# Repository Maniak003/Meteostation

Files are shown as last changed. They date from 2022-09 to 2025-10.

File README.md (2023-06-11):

<!DOCTYPE html>
<html lang="en" data-color-mode="auto" data-light-theme="light" data-dark-theme="dark">
  <head>
    <meta charset="utf-8">
  </head>
    <body class="logged-in env-production page-responsive page-blob" style="word-wrap: break-word;">
      <p> Meteostation with radiation monitor. </p>
      <a href="https://github.com/Maniak003/Meteostation/wiki" rel="nofollow">
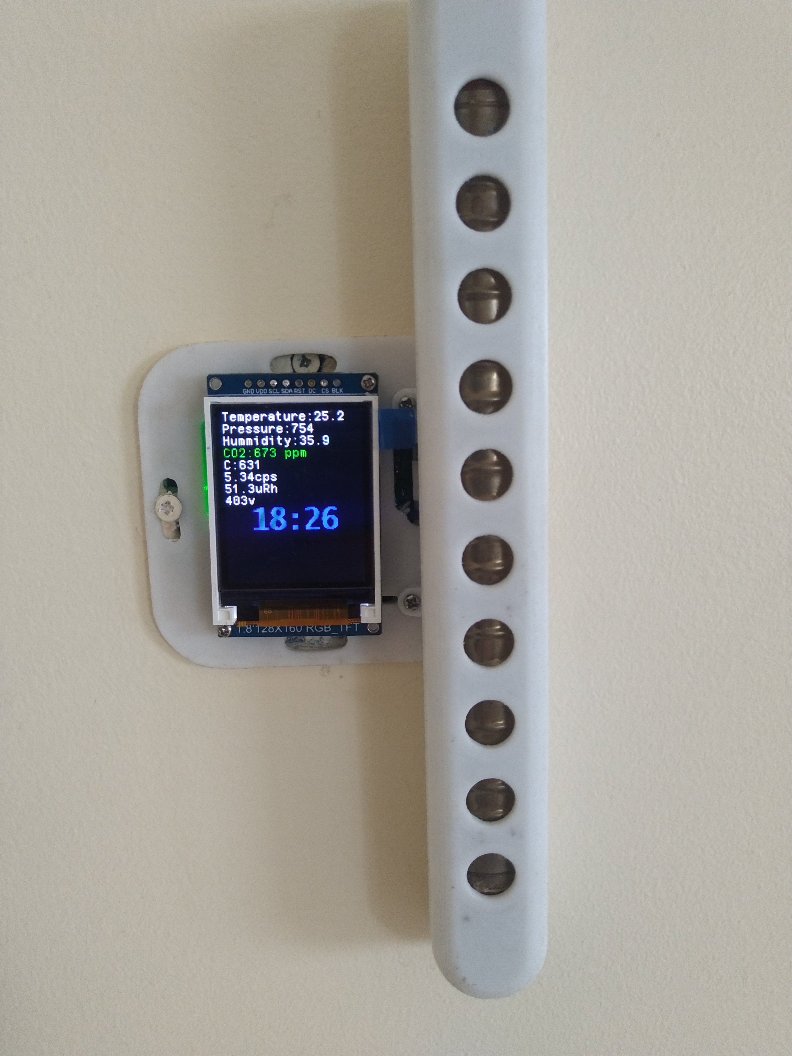
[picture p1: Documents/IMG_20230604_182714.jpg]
        
      </a>
      <a href="https://github.com/Maniak003/Meteostation/wiki" rel="nofollow">
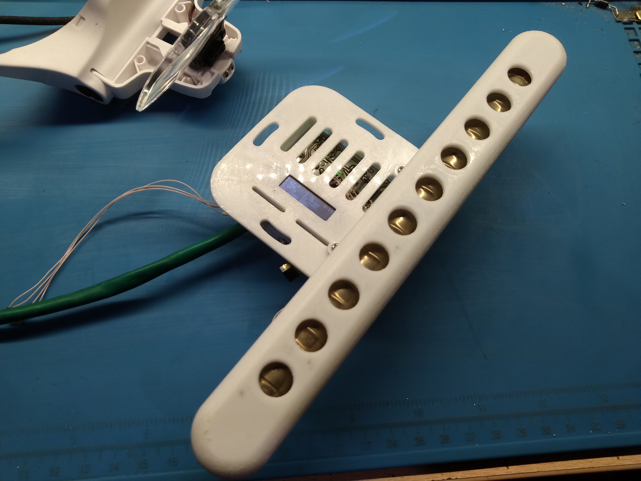
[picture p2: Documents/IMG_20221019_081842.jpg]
        
      </a>
      <a href="https://github.com/Maniak003/HVoltmeter/wiki" rel="nofollow">
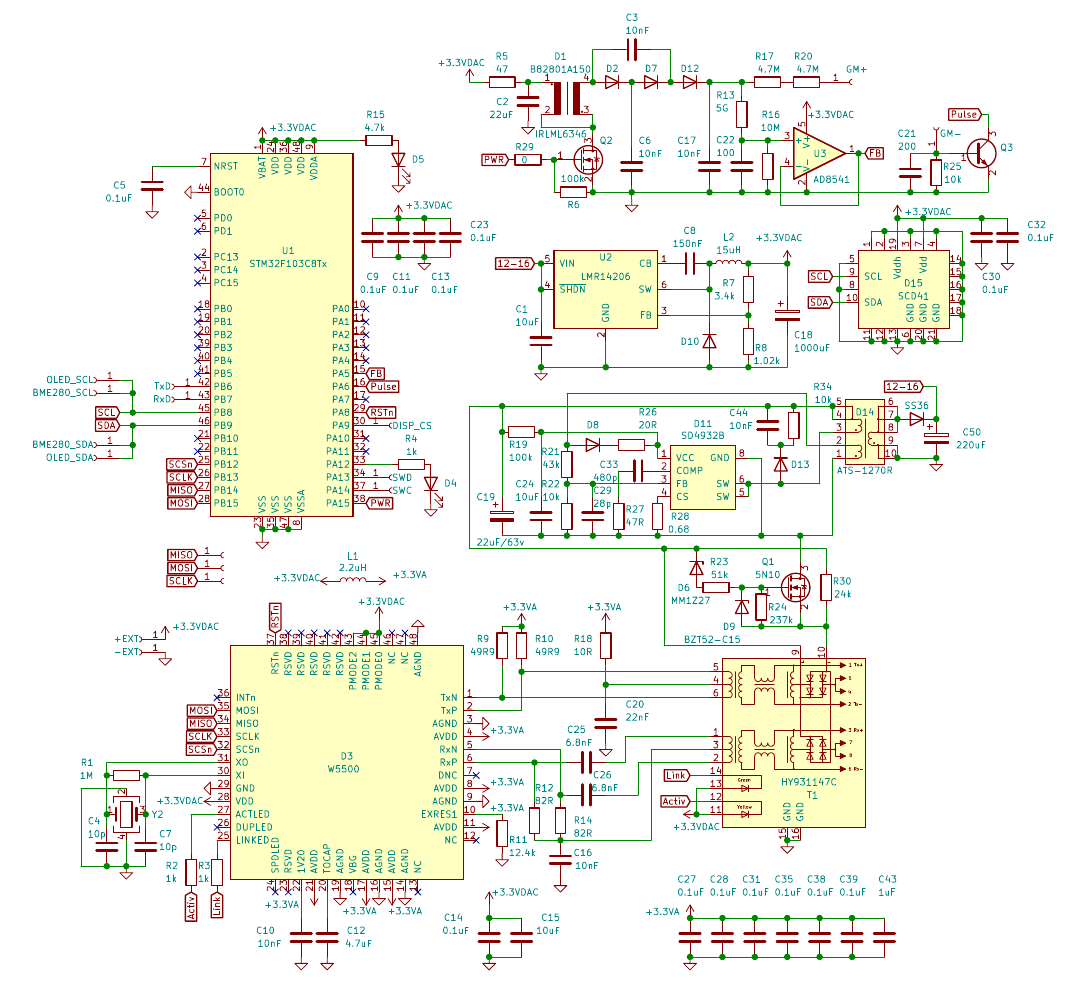
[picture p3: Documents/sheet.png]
        
      </a>
    </body>
</html>

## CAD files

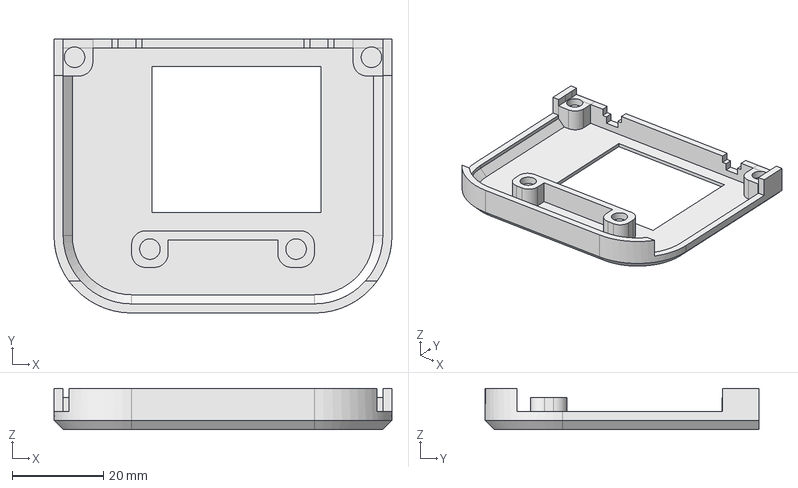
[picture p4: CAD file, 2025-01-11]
FreeCAD/face.FCStd
74.0 x 60.0 x 9.00 mm

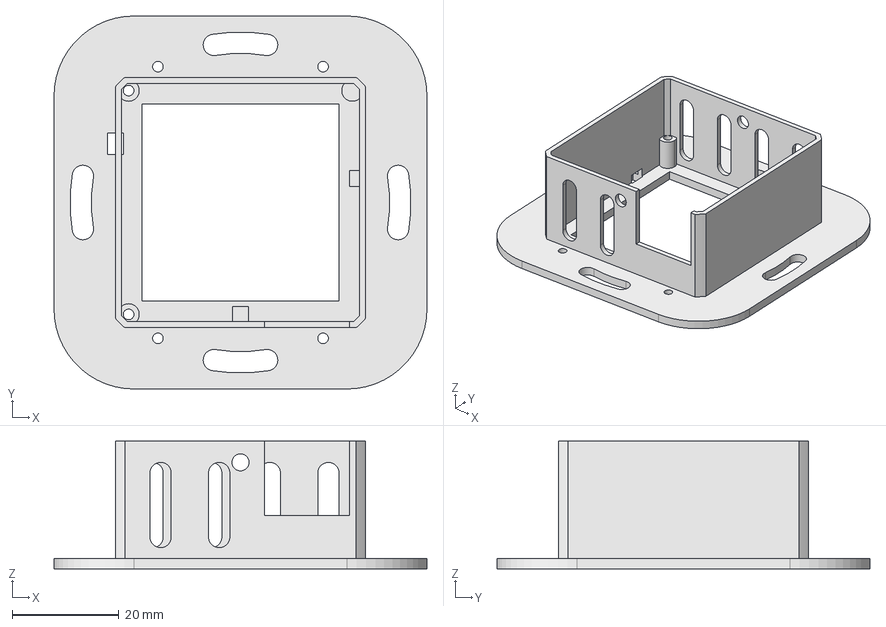
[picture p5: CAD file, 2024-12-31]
FreeCAD/box3.FCStd
70.0 x 70.0 x 24.0 mm

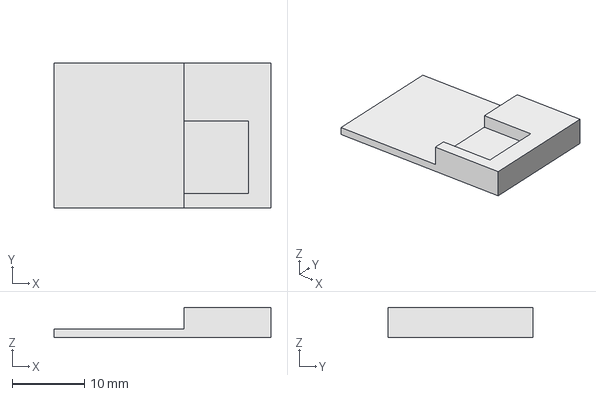
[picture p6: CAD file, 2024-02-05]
FreeCAD/co2holder.FCStd
30.0 x 20.0 x 4.20 mm

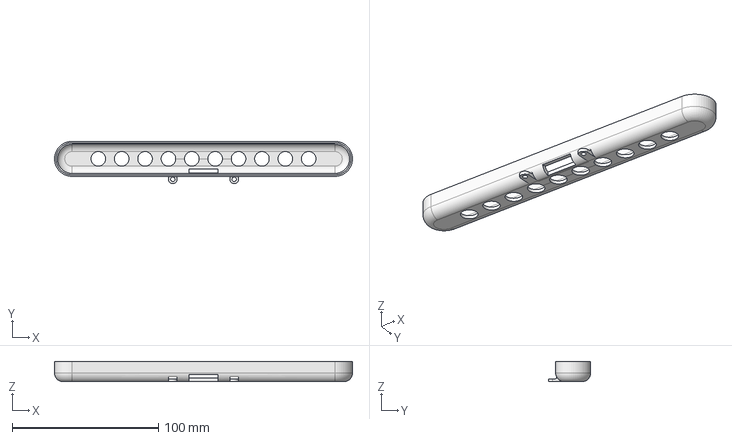
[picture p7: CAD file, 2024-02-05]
FreeCAD/GM_case.FCStd
204.0 x 29.0 x 14.0 mm

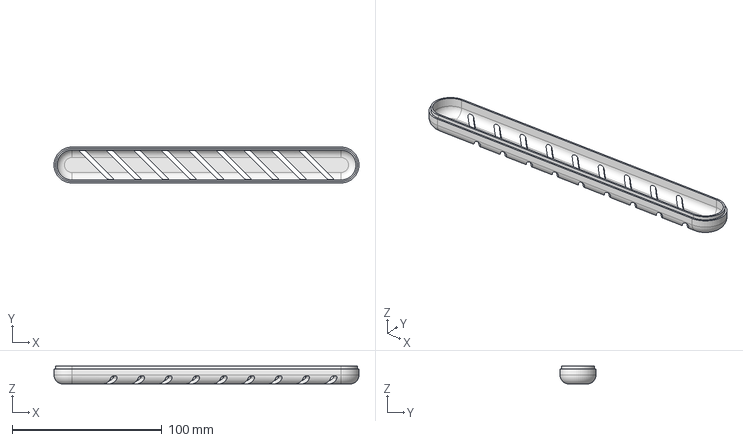
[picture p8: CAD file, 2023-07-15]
FreeCAD/GM_case_top-2.FCStd
204.0 x 24.0 x 12.0 mm

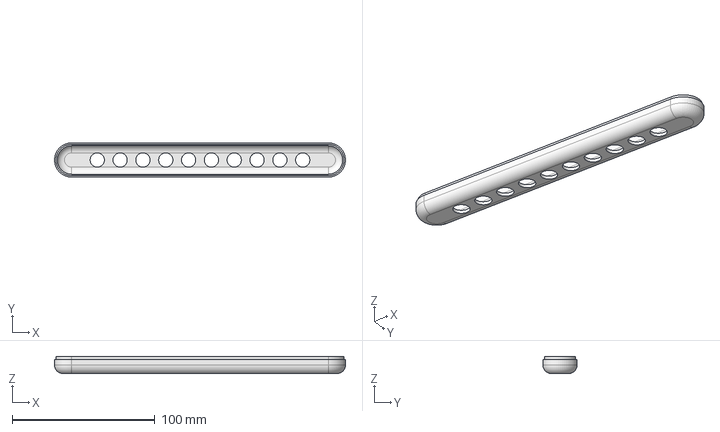
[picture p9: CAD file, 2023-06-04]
FreeCAD/GM_case_top.FCStd
204.0 x 24.0 x 12.0 mm

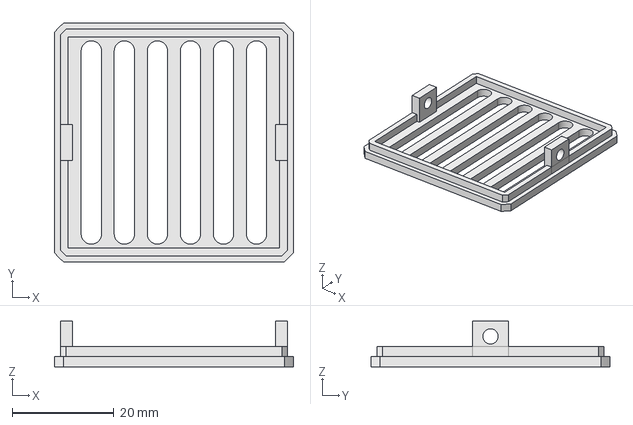
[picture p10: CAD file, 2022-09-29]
FreeCAD/cover.FCStd
47.0 x 47.0 x 9.00 mm

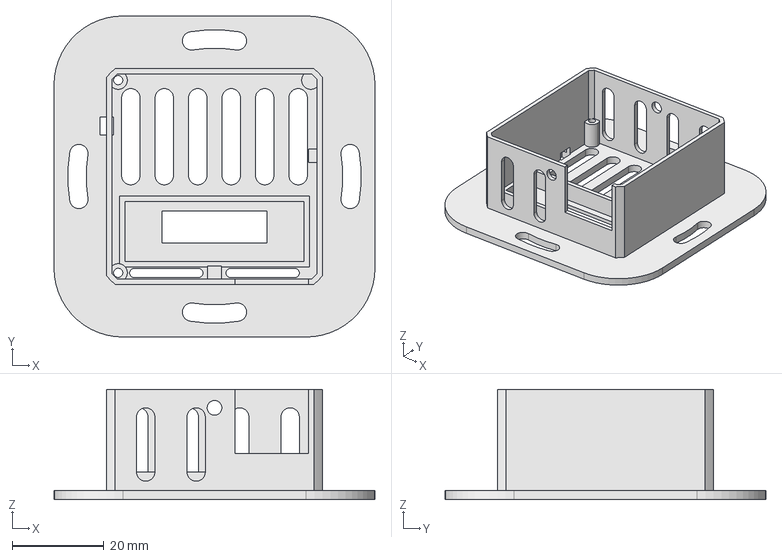
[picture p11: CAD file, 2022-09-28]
FreeCAD/box2.FCStd
70.0 x 70.0 x 24.0 mm

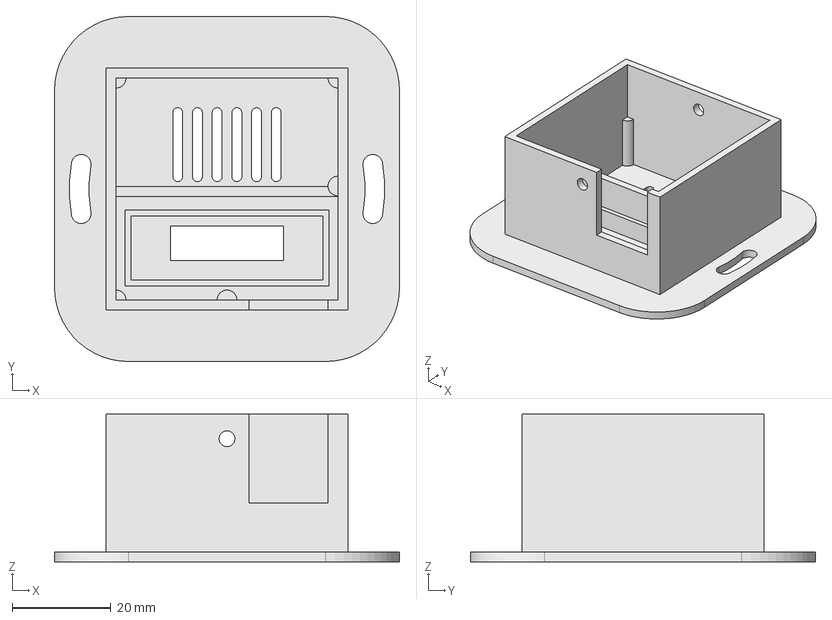
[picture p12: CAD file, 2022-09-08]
FreeCAD/box.FCStd
70.0 x 70.0 x 30.0 mm

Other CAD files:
FreeCAD/box.stl
FreeCAD/box2.stl

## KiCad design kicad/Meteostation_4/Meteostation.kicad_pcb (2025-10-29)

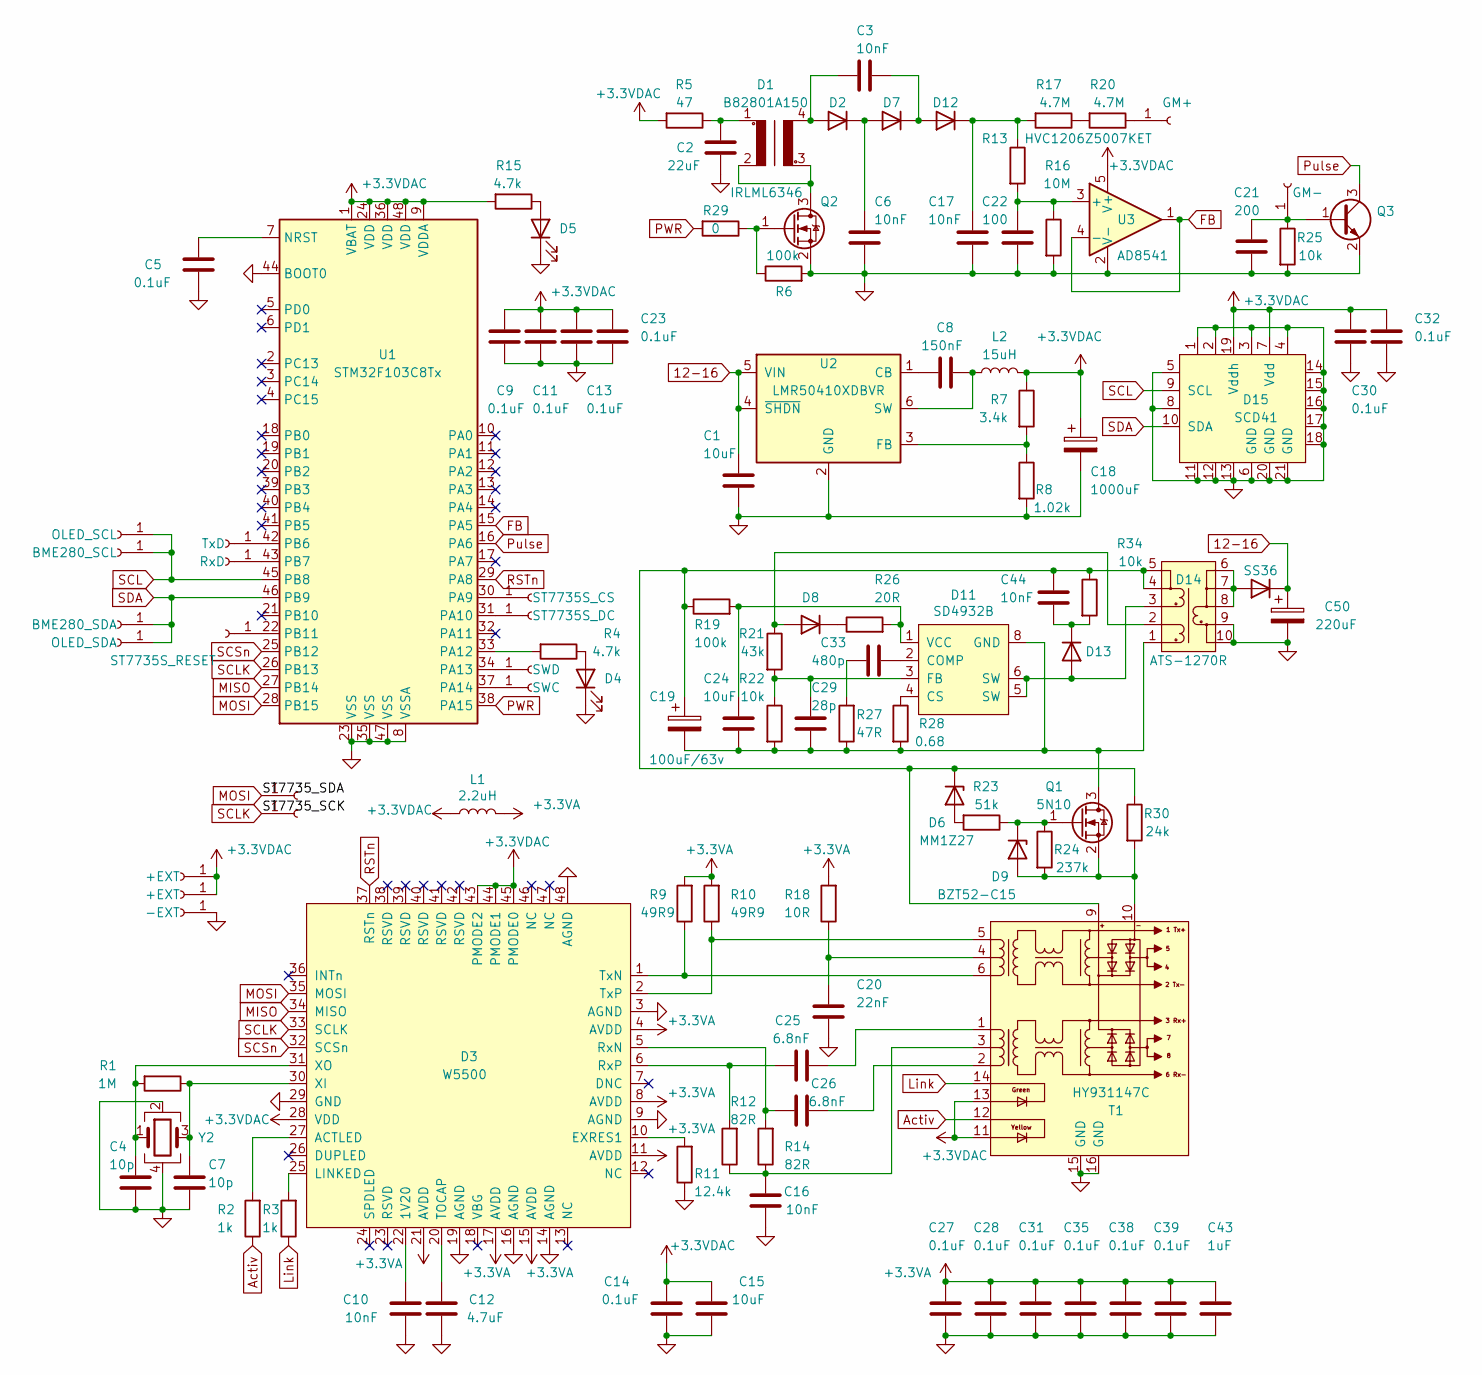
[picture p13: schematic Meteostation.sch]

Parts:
C1, C24: 10uF; C_0805_2012Metric
C2: 22uF; C_0805_2012Metric
C3, C6, C17: 10nF; C_1206_3216Metric
C4, C7: 10p; C_0402_1005Metric
C5, C14, C27, C28, C31, C35, C38, C39: 0.1uF; C_0402_1005Metric
C8: 150nF; C_0603_1608Metric
C9, C11, C13, C30, C32: 0.1uF; C_0603_1608Metric
C10: 10nF; C_0402_1005Metric
C12: 4.7uF; C_0402_1005Metric
C15: 10uF; C_0603_1608Metric
C16, C44: 10nF; C_0603_1608Metric
C18: 1000uF; CP_EIA-7343-15_Kemet-W
C19: 100uF/63v; CAP_horizontal
C20: 22nF; C_0603_1608Metric
C21: 200; C_0402_1005Metric
C22: 100; C_0402_1005Metric
C23: 0.1uF; C_0805_2012Metric
C25, C26: 6.8nF; C_0402_1005Metric
C29: 28p; C_0603_1608Metric
C33: 480p; C_0603_1608Metric
C43: 1uF; C_0402_1005Metric
C50: 220uF; CP_EIA-7343-15_Kemet-W
D1: B82801A150; B82801A1
D2, D7, D12: D; D_SOD-123
D3: W5500; LQFP-48_7x7mm_P0.5mm
D4, D5: LED; LED_0603_1608Metric
D6: MM1Z27; D_SOD-123
D8, D13: FR107W F7; D_SOD-123F
D9: BZT52-C15; D_SOD-123
D11: SD4932B; SOIC-8-N7_3.9x4.9mm_P1.27mm
D14: ATS-1270R; DA2257
D15: SCD41
D16: SS36; D_SMA
J1: TxD; ConnMini
J2: RxD; ConnMini
J3: BME280_SCL; SMD-CONN
J4: BME280_SDA; SMD-CONN
J5: +EXT; ConnMini
J6: +EXT; SMD-CONN
J7: -EXT; SMD-CONN
J8: mosi; ConnMini
J9: sclk; ConnMini
J10: GM+; SMD-CONN
J11: GM-; SMD-CONN
J12: SWD; ConnMini
J13: SWC; ConnMini
J14: ST7735S_CS; mini_conn
J15: OLED_SCL; SMD-CONN
J16: OLED_SDA; SMD-CONN
J17: ST7735S_DC; mini_conn
J18: ST7735S_RESET; mini_conn
L1: 2.2uH; L_0805_2012Metric
L2: 15uH; L_Abracon_ASPI-0630LR
Q1: 5N10; SOT-23
Q2: IRLML6346; SOT-23
Q3: Q_NPN_BEC; SOT-23
R1: 1M; R_0402_1005Metric
R2, R3: 1k; R_0402_1005Metric
R4: 4.7k; R_0402_1005Metric
R5: 47; R_1206_3216Metric
R6, R19: 100k; R_0603_1608Metric
R7: 3.4k; R_0603_1608Metric
R8: 1.02k; R_0603_1608Metric
R9, R10: 49R9; R_0603_1608Metric
R11: 12.4k; R_0402_1005Metric
R12, R14: 82R; R_0402_1005Metric
R13: HVC1206Z5007KET; R_1206_3216Metric
R15: 4.7k; R_0603_1608Metric
R16: 10M; R_0402_1005Metric
R17, R20: 4.7M; R_0603_1608Metric
R18: 10R; R_0603_1608Metric
R21: 43k; R_0603_1608Metric
R22, R34: 10k; R_0603_1608Metric
R23: 51k; R_0603_1608Metric
R24: 237k; R_0603_1608Metric
R25: 10k; R_0402_1005Metric
R26: 20R; R_0603_1608Metric
R27: 47R; R_0603_1608Metric
R28: 0.68; R_0603_1608Metric
R29: 0; R_1206_3216Metric
R30: 24k; R_0603_1608Metric
T1: HY931147C
U1: STM32F103C8Tx; LQFP-48_7x7mm_P0.5mm
U2: LMR50410XDBVR; SOT-23-6
U3: AD8541; TSOT-23-5
Y2: ECS-250-20-33 25MHz; Crystal_SMD_SeikoEpson_FA238-4Pin_3.2x2.5mm

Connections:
12-16: C1.1, C50.1, D16.1 (K), U2.4 (~SHDN), U2.5 (VIN)
+3.3VA: C27.1, C28.1, C31.1, C35.1, C38.1, C39.1, C43.1, D3.4 (AVDD), D3.8 (AVDD), D3.11 (AVDD), D3.15 (AVDD), D3.17 (AVDD), D3.21 (AVDD), L1.2, R9.2, R10.2, R18.2
+3.3VDAC: C9.1, C11.1, C13.1, C14.2, C15.2, C18.1, C23.1, C30.1, C32.1, D3.28 (VDD), D3.43 (PMODE2), D3.44 (PMODE1), D3.45 (PMODE0), D15.7 (Vdd), D15.19 (Vddh), J5.1, J6.1, L1.1, L2.2, R5.2, R7.1, R15.2, T1.11, T1.13, U1.1 (VBAT), U1.9 (VDDA), U1.24 (VDD), U1.36 (VDD), U1.48 (VDD), U3.5 (V+)
Activ: R2.1, T1.12
FB: U1.15 (PA5), U3.1, U3.4 (-)
GND: C1.2, C2.2, C4.2, C5.1, C6.2, C7.2, C9.2, C10.1, C11.2, C12.1, C13.2, C14.1, C15.1, C16.1, C17.2, C18.2, C20.2, C21.1, C22.1, C23.2, C27.2, C28.2, C30.2, C31.2, C32.2, C35.2, C38.2, C39.2, C43.2, C50.2, D3.3 (AGND), D3.9 (AGND), D3.14 (AGND), D3.16 (AGND), D3.19 (AGND), D3.29 (GND), D3.48 (AGND), D4.1 (K), D5.1 (K), D14.9, D14.10, D15.1, D15.2, D15.3, D15.4, D15.5, D15.6 (GND), D15.8, D15.11, D15.12, D15.13, D15.14, D15.15, D15.16, D15.17, D15.18, D15.20 (GND), D15.21 (GND), J7.1, Q2.2 (S), Q3.2 (E), R6.2, R8.2, R11.1, R16.2, R25.2, T1.15 (GND), T1.16 (GND), U1.8 (VSSA), U1.23 (VSS), U1.35 (VSS), U1.44 (BOOT0), U1.47 (VSS), U2.2 (GND), U3.2 (V-), Y2.2, Y2.4
Link: R3.1, T1.14
MISO: D3.34 (MISO), U1.27 (PB14)
MOSI: D3.35 (MOSI), J8.1, U1.28 (PB15)
unnamed: C2.1, D1.1, R5.1
unnamed: C16.2, R12.1, R14.1, T1.3
unnamed: C20.1, R18.1, T1.4
unnamed: C25.2, T1.1
unnamed: C26.2, T1.2
unnamed: C33.2, R27.2
unnamed: C3.2, D1.4, D2.2 (A)
unnamed: C6.1, D2.1 (K), D7.2 (A)
unnamed: C10.2, D3.22 (1V20)
unnamed: D3.27 (ACTLED), R2.2
unnamed: D3.10 (EXRES1), R11.2
unnamed: D3.25 (LINKED), R3.2
unnamed: C26.1, D3.5 (RxN), R14.2
unnamed: C25.1, D3.6 (RxP), R12.2
unnamed: C12.2, D3.20 (TOCAP)
unnamed: D3.1 (TxN), R9.1, T1.6
unnamed: D3.2 (TxP), R10.1, T1.5
unnamed: C7.1, D3.30 (XI), R1.1, Y2.3
unnamed: C4.1, D3.31 (XO), R1.2, Y2.1
unnamed: D4.2 (A), R4.1
unnamed: D5.2 (A), R15.1
unnamed: D6.2 (A), R23.2
unnamed: C19.1, C44.1, D6.1 (K), D14.4, D14.5, R19.1, R30.1, R34.1, T1.9
unnamed: D8.2 (A), D14.2, R21.1
unnamed: D8.1 (K), R26.1
unnamed: D9.2 (A), Q1.2 (S), R24.2, R30.2, T1.10
unnamed: D9.1 (K), Q1.1 (G), R23.1, R24.1
unnamed: C33.1, D11.2 (COMP)
unnamed: D11.4 (CS), R28.1
unnamed: C29.1, D11.3 (FB), R21.2, R22.1
unnamed: C19.2, C24.2, C29.2, D11.8 (GND), D14.1, Q1.3 (D), R22.2, R27.1, R28.2
unnamed: C24.1, D11.1 (VCC), R19.2, R26.2
unnamed: C3.1, D7.1 (K), D12.2 (A)
unnamed: C17.1, D12.1 (K), R13.1, R17.2
unnamed: D11.5 (SW), D11.6 (SW), D13.2 (A), D14.3
unnamed: C44.2, D13.1 (K), R34.2
unnamed: D14.6, D14.7, D14.8, D16.2 (A)
unnamed: J1.1, U1.42 (PB6)
unnamed: J2.1, U1.43 (PB7)
unnamed: J10.1, R20.1
unnamed: C21.2, J11.1, Q3.1 (B), R25.1
unnamed: J12.1, U1.34 (PA13)
unnamed: J13.1, U1.37 (PA14)
unnamed: J14.1, U1.30 (PA9)
unnamed: J17.1, U1.31 (PA10)
unnamed: J18.1, U1.22 (PB11)
unnamed: D1.2, D1.3, Q2.3 (D)
unnamed: Q2.1 (G), R6.1, R29.1
unnamed: R17.1, R20.2
unnamed: C5.2, U1.7 (NRST)
unnamed: R4.2, U1.33 (PA12)
unnamed: C8.1, U2.1 (CB)
unnamed: R7.2, R8.1, U2.3 (FB)
unnamed: C8.2, L2.1, U2.6 (SW)
unnamed: C22.2, R13.2, R16.1, U3.3 (+)
PWR: R29.2, U1.38 (PA15)
Pulse: Q3.3 (C), U1.16 (PA6)
RSTn: D3.37 (RSTn), U1.29 (PA8)
SCL: D15.9 (SCL), J3.1, J15.1, U1.45 (PB8)
SCLK: D3.33 (SCLK), J9.1, U1.26 (PB13)
SCSn: D3.32 (SCSn), U1.25 (PB12)
SDA: D15.10 (SDA), J4.1, J16.1, U1.46 (PB9)

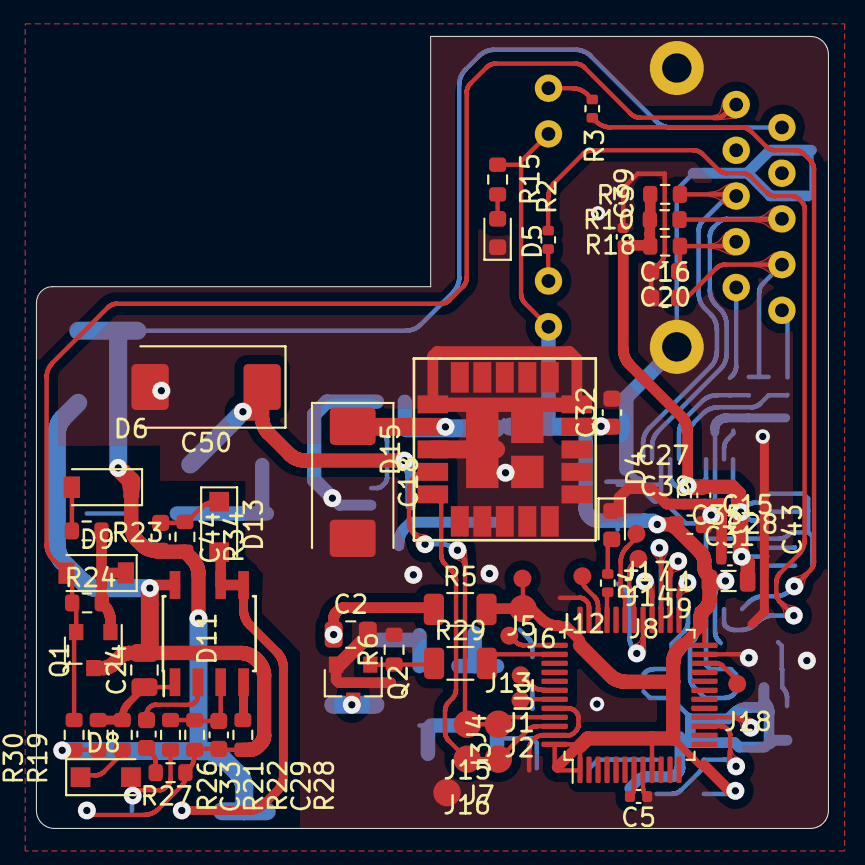
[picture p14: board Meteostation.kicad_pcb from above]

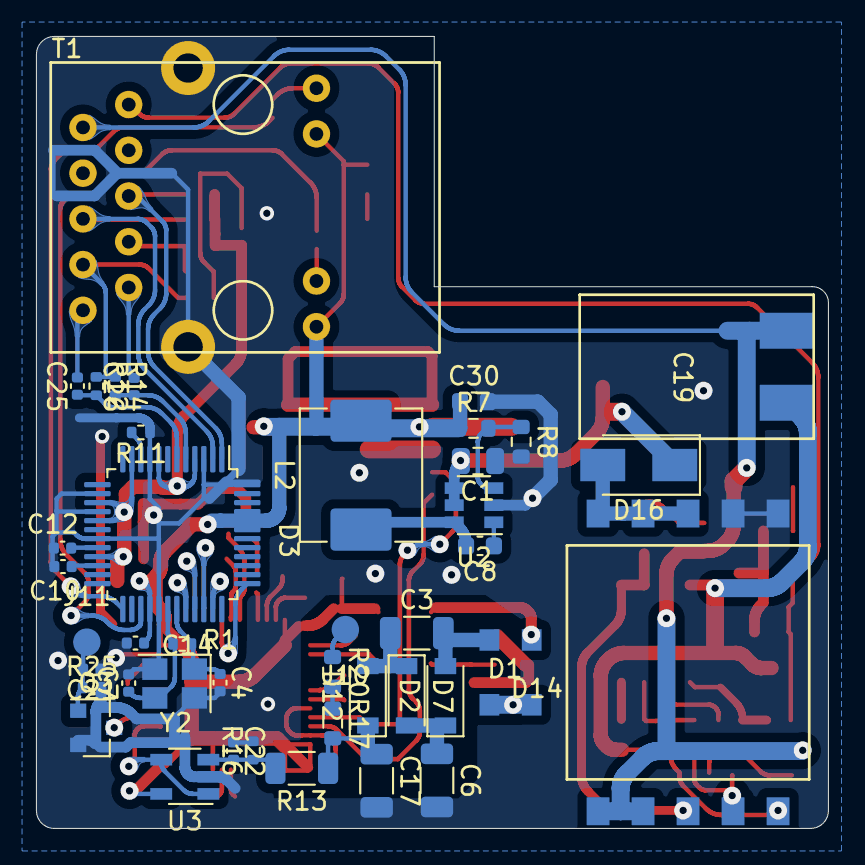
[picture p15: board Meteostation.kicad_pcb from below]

Board: 2 copper layers, 44.0 x 44.0 mm, 109 parts (42 on the bottom side), 71 nets.

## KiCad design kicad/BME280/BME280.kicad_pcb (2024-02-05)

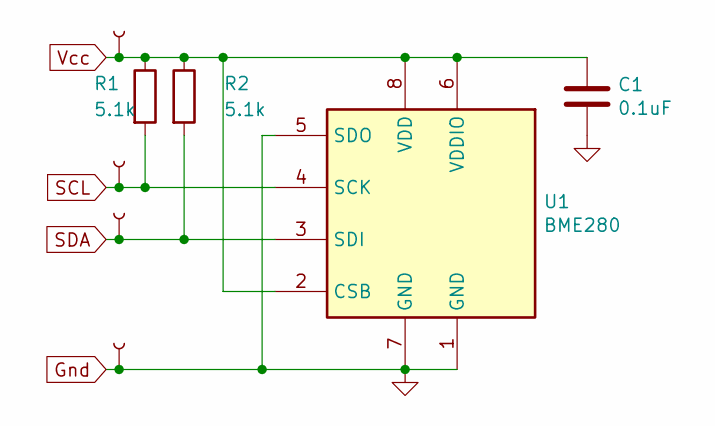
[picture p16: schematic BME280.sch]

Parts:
C1: 0.1uF; C_0402_1005Metric
J1, J2, J3, J4: Conn; ConnMini
R1, R2: 5.1k; R_0402_1005Metric
U1: BME280; Bosch_LGA-8_2.5x2.5mm_P0.65mm_ClockwisePinNumbering

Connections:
Gnd: C1.2, J4.1, U1.1 (GND), U1.5 (SDO), U1.7 (GND)
SCL: J2.1, R1.2, U1.4 (SCK)
SDA: J3.1, R2.2, U1.3 (SDI)
Vcc: C1.1, J1.1, R1.1, R2.1, U1.2 (CSB), U1.6 (VDDIO), U1.8 (VDD)

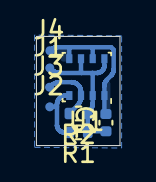
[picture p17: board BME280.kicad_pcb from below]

Board: 2 copper layers, 4.6 x 6.1 mm, 8 parts (8 on the bottom side), 4 nets.

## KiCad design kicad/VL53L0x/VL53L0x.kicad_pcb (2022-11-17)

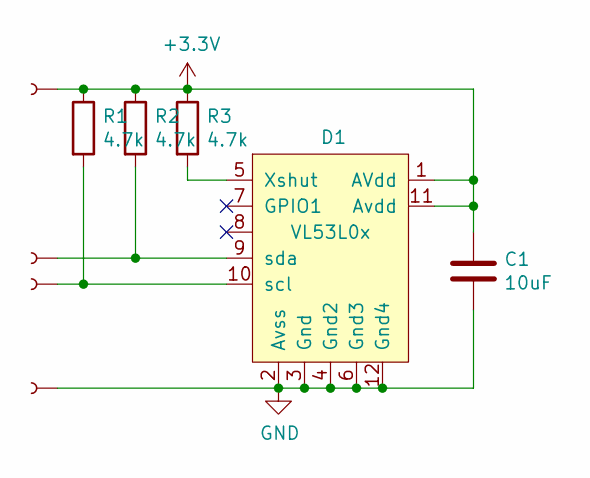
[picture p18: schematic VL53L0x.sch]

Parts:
C1: 10uF; C_0402_1005Metric
D1: VL53L0x
J1, J2, J3, J4: Conn; ConnMini
R1, R2, R3: 4.7k; R_0402_1005Metric

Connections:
+3V3: C1.1, D1.1 (AVdd), D1.11 (Avdd), J1.1, R1.1, R2.1, R3.1
GND: C1.2, D1.2 (Avss), D1.3 (Gnd), D1.4 (Gnd2), D1.6 (Gnd3), D1.12 (Gnd4), J4.1
unnamed: D1.5 (Xshut), R3.2
unnamed: D1.9 (sda), J2.1, R2.2
unnamed: D1.10 (scl), J3.1, R1.2

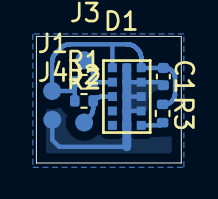
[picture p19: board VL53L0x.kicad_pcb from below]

Board: 2 copper layers, 8.1 x 7.0 mm, 9 parts (9 on the bottom side), 5 nets.

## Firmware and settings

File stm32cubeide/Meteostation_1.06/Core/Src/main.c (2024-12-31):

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
/* Includes ------------------------------------------------------------------*/
#include "main.h"

/* USER CODE BEGIN PTD */
#ifndef PUBLIC_VAR
#define PUBLIC_VAR

uint32_t fastCounter, CO2Counter, CO2Interval ;
uint16_t hvLevel;
bool gm_ready;
float temperature, pressure, humidity;
char ZabbixHostName[255];
#endif

/* USER CODE END PTD */

ADC_HandleTypeDef hadc1;
DMA_HandleTypeDef hdma_adc1;

I2C_HandleTypeDef hi2c1;

IWDG_HandleTypeDef hiwdg;

RTC_HandleTypeDef hrtc;

SPI_HandleTypeDef hspi2;

TIM_HandleTypeDef htim1;
TIM_HandleTypeDef htim4;

UART_HandleTypeDef huart1;

/* USER CODE BEGIN PV */
HAL_StatusTypeDef	flash_ok;
char uart_buffer[10] = {0,};
char buff_anem[50] = {0,};
char SndBuffer[200] = {0,};
char text1306[16];
uint16_t gm_counter = 0;
uint32_t gm_interval = 0, ntp_interval = 0, zabb_interval = 0, anem_interval = 0;
float gm_cps = 0;
sSensorMeasurement_t messuremetData;
uint16_t CO2;

#ifdef ZABBIX_ENABLE
wiz_NetInfo net_info = {
	.mac  = { MAC_ADDRESS },
	.dhcp = NETINFO_DHCP
};
uint8_t ntp_server[4] = {192, 168, 1, 1/*188, 246, 226, 6*/};
uint8_t gDATABUF[DATA_BUF_SIZE];
datetime timeNTP;
#endif

RTC_TimeTypeDef sTime = {0};
RTC_DateTypeDef DateToUpdate = {0};
char trans_str[64] = {0,};
bool gm_ready = FALSE;
bool first_start = TRUE, fist_time_show = TRUE, first_time_anem = TRUE;
int tot_bytes = 0;

/* USER CODE END PV */

void SystemClock_Config(void);
static void MX_GPIO_Init(void);
static void MX_DMA_Init(void);
static void MX_USART1_UART_Init(void);
static void MX_I2C1_Init(void);
static void MX_SPI2_Init(void);
static void MX_IWDG_Init(void);
static void MX_ADC1_Init(void);
static void MX_TIM1_Init(void);
static void MX_RTC_Init(void);
static void MX_TIM4_Init(void);
/* USER CODE BEGIN 0 */
#ifdef ZABBIX_ENABLE

#ifdef ZABBIX_DEBUG
void UART_Printf(const char* fmt, ...) {
	char buff[256];
	va_list args;
	va_start(args, fmt);
	vsnprintf(buff, sizeof(buff), fmt, args);
	HAL_UART_Transmit(&huart1, (uint8_t*) buff, strlen(buff), HAL_MAX_DELAY);
	va_end(args);
}
#endif


void W5500_Select(void) {
	HAL_GPIO_WritePin(Eth_CS_GPIO_Port, Eth_CS_Pin, GPIO_PIN_RESET);
}

void W5500_Unselect(void) {
	HAL_GPIO_WritePin(Eth_CS_GPIO_Port, Eth_CS_Pin, GPIO_PIN_SET);
}

void W5500_ReadBuff(uint8_t* buff, uint16_t len) {
	HAL_SPI_Receive(&hspi2, buff, len, HAL_MAX_DELAY);
}

void W5500_WriteBuff(uint8_t* buff, uint16_t len) {
	HAL_SPI_Transmit(&hspi2, buff, len, HAL_MAX_DELAY);
}

uint8_t W5500_ReadByte(void) {
	uint8_t byte;
	W5500_ReadBuff(&byte, sizeof(byte));
	return byte;
}

void W5500_WriteByte(uint8_t byte) {
	W5500_WriteBuff(&byte, sizeof(byte));
}

volatile bool ip_assigned = false;

void Callback_IPAssigned(void) {
#ifdef ZABBIX_DEBUG
	UART_Printf("Callback: IP assigned! Leased time: %d sec\r\n", getDHCPLeasetime());
#endif
    ip_assigned = true;
}

void Callback_IPConflict(void) {
#ifdef ZABBIX_DEBUG
    UART_Printf("Callback: IP conflict!\r\n");
#endif
}

// 1K should be enough, see https://forum.wiznet.io/t/topic/1612/2
uint8_t dhcp_buffer[1024];
// 1K seems to be enough for this buffer as well
//uint8_t dns_buffer[1024];

/*
 * addr -- IP address zabbix server, dhcp option 224.
 * Settings for isc-dhcp-server:
 * 		option zabbix-server-ip code 224 = ip-address ;
 * 		option zabix-host-name code 225 = string ;
 * 		host anemometr {
 *      	hardware ethernet 00:11:22:33:44:xx;
 *      	fixed-address 192.168.1.24;
 *       	option zabbix-server-ip 192.168.1.6;
 *       	option zabix-host-name "Ed";
 * 		}
 *
 * key -- Zabbix key: {ALTIM_DIRECT, ALTIM_SPEED}
 *
 * value -- Float value of key.
*/
uint8_t sendToZabbix(uint8_t * addr, char * host, char * key, float value) {
#ifdef ZABBIX_DEBUG
    UART_Printf("Creating socket...\r\n");
#endif
    uint8_t tcp_socket = TCP_SOCKET;
    uint8_t code = socket(tcp_socket, Sn_MR_TCP, 10888, 0);
    if(code != tcp_socket) {
	#ifdef ZABBIX_DEBUG
        UART_Printf("socket() failed, code = %d\r\n", code);
	#endif
        return(-1);
    }
#ifdef ZABBIX_DEBUG
    UART_Printf("Socket created, connecting...\r\n");
#endif
    code = connect(tcp_socket, addr, ZABBIXPORT);
    if(code != SOCK_OK) {
	#ifdef ZABBIX_DEBUG
        UART_Printf("connect() failed, code = %d\r\n", code);
	#endif
        close(tcp_socket);
        return(-2);
    }
#ifdef ZABBIX_DEBUG
    UART_Printf("Connected, sending ZABBIX request...\r\n");
#endif
    {
    	char req[ZABBIXMAXLEN];
    	char str[ZABBIXMAXLEN - 13];
    	sprintf(str, "{\"request\":\"sender data\",\"data\":[{\"host\":\"%.20s\",\"key\":\"%s\",\"value\":\"%f\"}]}", host, key, value);
    	req[0] = 'Z';
    	req[1] = 'B';
		req[2] = 'X';
		req[3] = 'D';
		req[4] = 0x01;
		req[5] = strlen(str);
		req[6] = 0;
		req[7] = 0;
		req[8] = 0;
		req[9] = 0;
		req[10] = 0;
		req[11] = 0;
		req[12] = 0;
		strcpy(req + 13, str);
        //char req[] = "ZBXD\1\0\0\0\0\0\0\0\0{\"request\":\"sender data\",\"data\":[{\"host\":\"Ed\",\"key\":\"ALTIM_DIRECT\",\"value\":\"10\"}]}";
        uint8_t len = req[5] + 13;
        uint8_t* buff = (uint8_t*)&req;
        while(len > 0) {
		#ifdef ZABBIX_DEBUG
            UART_Printf("Sending %d bytes, data length %d bytes...\r\n", len, req[5]);
		#endif
            int32_t nbytes = send(tcp_socket, buff, len);
            if(nbytes <= 0) {
			#ifdef ZABBIX_DEBUG
                UART_Printf("send() failed, %d returned\r\n", nbytes);
			#endif
                close(tcp_socket);
                return(-3);
            }
			#ifdef ZABBIX_DEBUG
            UART_Printf("%d b sent!\r\n", nbytes);
			#endif
            len -= nbytes;
        }
    }
    /* Read data from Zabbix */
	#ifdef ZABBIX_DEBUG
		UART_Printf("Read.\r\n");
		{
			char buff[32];
			for(;;) {
				int32_t nbytes = recv(tcp_socket, (uint8_t*)&buff, sizeof(buff)-1);
				if(nbytes == SOCKERR_SOCKSTATUS) {
					UART_Printf("\r\nDisconnect.\r\n");
					break;
				}

				if(nbytes <= 0) {
					UART_Printf("\r\nrecv() failed, %d\r\n", nbytes);
					break;
				}

				buff[nbytes] = '\0';
				UART_Printf("%s", buff);
			}
		}

		UART_Printf("Closing socket.\r\n");
	#endif
    close(tcp_socket);
    return(0);
}

void getDataFromAnemometer () {
	//ANEMOMETERPORT
    uint8_t tcp_socket = ANM_SOCKET;
    uint8_t code = socket(tcp_socket, Sn_MR_TCP, 10889, 0);
    tot_bytes = 0;
    if(code != tcp_socket) {
        return;
    }
    code = connect(tcp_socket, net_info.zabbix, ANEMOMETERPORT);
    if(code != SOCK_OK) {
        close(tcp_socket);
        return;
    }
	for(;;) {
		int32_t nbytes = recv(tcp_socket, (uint8_t*) &buff_anem, sizeof(buff_anem) - 1);
		tot_bytes += nbytes;
		if(nbytes == SOCKERR_SOCKSTATUS) {
			break;
		}

	}
	if(tot_bytes > 3) {
	}
	close(tcp_socket);
}


void init_w5500() {
	#ifdef ZABBIX_DEBUG
    UART_Printf("\r\ninit() called!\r\n");
    UART_Printf("W5500 callbacks...\r\n");
	#endif
    reg_wizchip_cs_cbfunc(W5500_Select, W5500_Unselect);
    reg_wizchip_spi_cbfunc(W5500_ReadByte, W5500_WriteByte);
    reg_wizchip_spiburst_cbfunc(W5500_ReadBuff, W5500_WriteBuff);
	#ifdef ZABBIX_DEBUG
    UART_Printf("wizchip_init()...\r\n");
	#endif
    uint8_t rx_tx_buff_sizes[] = {2, 2, 2, 2, 2, 2, 2, 2};
    wizchip_init(rx_tx_buff_sizes, rx_tx_buff_sizes);
	#ifdef ZABBIX_DEBUG
    UART_Printf("DHCP_init()...\r\n");
	#endif

    // set MAC address before using DHCP
    setSHAR(net_info.mac);
    DHCP_init(DHCP_SOCKET, dhcp_buffer);
	#ifdef ZABBIX_DEBUG
    UART_Printf("DHCP callbacks...\r\n");
	#endif
    reg_dhcp_cbfunc(
        Callback_IPAssigned,
        Callback_IPAssigned,
        Callback_IPConflict
    );
	#ifdef ZABBIX_DEBUG
    UART_Printf("DHCP_run()...\r\n");
	#endif
    // actually should be called in a loop, e.g. by timer
    uint32_t ctr = 10000;
    while((!ip_assigned) && (ctr > 0)) {
        DHCP_run();
        ctr--;
        HAL_Delay(300);
    }
    if(!ip_assigned) {
		#ifdef ZABBIX_DEBUG
        UART_Printf("\r\nIP was not assigned :(\r\n");
		#endif
        return;
    }

    getIPfromDHCP(net_info.ip);
    getGWfromDHCP(net_info.gw);
    getSNfromDHCP(net_info.sn);
    getZABBIXfromDHCP(net_info.zabbix);
    getHostNamefromDHCP(net_info.hostname);
    //getTimeSrvfromDHCP(net_info.tmsrv);
    getSNTPSrvfromDHCP(net_info.tmsrv);
    if (net_info.hostname[0] == '\0') {
    	sprintf(ZabbixHostName, "%s", ZABBIXAGHOST);
    } else {
    	sprintf(ZabbixHostName, "%s", net_info.hostname);
    }

    //uint8_t dns[4];
    //getDNSfromDHCP(dns);
	#ifdef ZABBIX_DEBUG
    UART_Printf("IP:  %d.%d.%d.%d\r\nGW:  %d.%d.%d.%d\r\nNet: %d.%d.%d.%d\r\nZabbix: %d.%d.%d.%d\r\nHostName:%s\r\n",
        net_info.ip[0], net_info.ip[1], net_info.ip[2], net_info.ip[3],
        net_info.gw[0], net_info.gw[1], net_info.gw[2], net_info.gw[3],
        net_info.sn[0], net_info.sn[1], net_info.sn[2], net_info.sn[3],
        net_info.zabbix[0], net_info.zabbix[1], net_info.zabbix[2], net_info.zabbix[3],
		ZabbixHostName
    );
    UART_Printf("Calling wizchip_setnetinfo()...\r\n");
	#endif
    wizchip_setnetinfo(&net_info);

}
#endif

/*
 * Function for control SCD41
 */
void setSleepMode(uint16_t mode) {
  SCDwriteData(mode, NULL, 0);
  if(SCD4X_WAKE_UP == mode)
    HAL_Delay(20);   // Give it some time to switch mode
}

uint16_t performSelfTest(void) {
  SCDwriteData(SCD4X_PERFORM_SELF_TEST, NULL, 0);
  HAL_Delay(10000);
  uint8_t buf[3] = {0};
  return SCD4X_CONCAT_BYTES(buf[0], buf[1]);
}

void moduleReinit(void) {
  SCDwriteData(SCD4X_REINIT, NULL, 0);
  HAL_Delay(20);
}

void performFactoryReset(void) {
  SCDwriteData(SCD4X_PERFORM_FACTORY_RESET, NULL, 0);
  HAL_Delay(1200);
}

/*
 * Measurement Function for SCD41
 */

void measureSingleShot(uint16_t mode) {
  SCDwriteData(mode, NULL, 0);
  if(SCD4X_MEASURE_SINGLE_SHOT == mode) {
	  HAL_Delay(5000);
  } else if(SCD4X_MEASURE_SINGLE_SHOT_RHT_ONLY == mode) {
	  HAL_Delay(50);
  }
}

void enablePeriodMeasure(uint16_t mode) {
  SCDwriteData(mode, NULL, 0);
  if(SCD4X_STOP_PERIODIC_MEASURE == mode)
	HAL_Delay(500);   // Give it some time to switch mode
}

bool getDataReadyStatus(void) {
  uint8_t buf[3] = {0};
  SCDreadData(SCD4X_GET_DATA_READY_STATUS, buf, sizeof(buf));
  if(0x0000 == (SCD4X_CONCAT_BYTES(buf[0], buf[1]) & 0x7FF)){
    return false;
  }
  return true;
}

/*
void setTempComp(float tempComp) {
  uint16_t data = (uint16_t)(tempComp * ((uint32_t)1 << 16) / 175);
  uint8_t * sendPack  = pack(data);
  SCDwriteData(SCD4X_SET_TEMPERATURE_OFFSET, sendPack, 3);
  free(sendPack);
}

float getTempComp(void) {
  uint8_t buf[3] = {0};
  SCDreadData(SCD4X_GET_TEMPERATURE_OFFSET, buf, sizeof(buf));
  if(buf[2] != calcCRC(SCD4X_CONCAT_BYTES(buf[0], buf[1]))) {
    //DBG("The crc failed!");
  }
  return 175 * (float)( SCD4X_CONCAT_BYTES(buf[0], buf[1]) ) / ((uint32_t)1 << 16);
}

void setSensorAltitude(uint16_t altitude) {
  uint8_t * sendPack = pack(altitude);
  SCDwriteData(SCD4X_SET_SENSOR_ALTITUDE, sendPack, 3);
  free(sendPack);
}

uint16_t getSensorAltitude(void) {
  uint8_t buf[3] = {0};
  SCDreadData(SCD4X_GET_SENSOR_ALTITUDE, buf, sizeof(buf));
  return SCD4X_CONCAT_BYTES(buf[0], buf[1]);
}

void setAmbientPressure(uint32_t ambientPressure) {
  uint16_t data = (uint16_t)(ambientPressure / 100);
  uint8_t * sendPack = pack(data);
  SCDwriteData(SCD4X_SET_AMBIENT_PRESSURE, sendPack, 3);
  free(sendPack);
}

int16_t performForcedRecalibration(uint16_t CO2ppm) {
  uint8_t * sendPack = pack(CO2ppm);
  SCDwriteData(SCD4X_PERFORM_FORCED_RECALIB, sendPack, 3);
  free(sendPack);
  HAL_Delay(400);   // command execution time
  uint8_t buf[3] = {0};
  return (int16_t)(SCD4X_CONCAT_BYTES(buf[0], buf[1]) - 0x8000);
}

void setAutoCalibMode(bool mode) {
  uint16_t data = 0;
  if(mode) {
    data = 1;
  }
  uint8_t * sendPack = pack(data);
  SCDwriteData(SCD4X_SET_AUTOMATIC_CALIB, sendPack, 3);
  free(sendPack);
}

bool getAutoCalibMode(void) {
  uint8_t buf[3] = {0};
  SCDreadData(SCD4X_GET_AUTOMATIC_CALIB, buf, sizeof(buf));
  if(0x0000 == SCD4X_CONCAT_BYTES(buf[0], buf[1])){
    return false;
  }
  return true;
}
*/

void persistSettings(void) {
  SCDwriteData(SCD4X_PERSIST_SETTINGS, NULL, 0);
  HAL_Delay(800);
}

bool getSerialNumber(uint16_t * wordBuf) {
  bool ret = true;
  uint8_t buf[9] = {0};
  if(sizeof(buf) != SCDreadData(SCD4X_GET_SERIAL_NUMBER, buf, sizeof(buf))) {
    ret = false;
  }
  wordBuf[0] = SCD4X_CONCAT_BYTES(buf[0], buf[1]);
  wordBuf[1] = SCD4X_CONCAT_BYTES(buf[3], buf[4]);
  wordBuf[2] = SCD4X_CONCAT_BYTES(buf[6], buf[7]);
  return ret;
}

/*
uint8_t calcCRC(uint16_t data) {
  uint16_t current_byte;
  uint8_t crc = SCD4X_CRC8_INIT;
  uint8_t crc_bit;
  uint8_t buf[2] = {(uint8_t)((data >> 8) & 0xFF), (uint8_t)(data & 0xFF)};

  // calculates 8-Bit checksum with given polynomial
  for (current_byte = 0; current_byte < 2; ++current_byte) {
    crc ^= (buf[current_byte]);
    for (crc_bit = 8; crc_bit > 0; --crc_bit) {
      if (crc & 0x80)
        crc = (crc << 1) ^ SCD4X_CRC8_POLYNOMIAL;
      else
        crc = (crc << 1);
    }
  }
  return crc;
}

uint8_t * DFRobot_SCD4X_pack(uint16_t data) {
  uint8_t * pBuf = (uint8_t *)malloc(sizeof(uint8_t) * 3);
  memset(pBuf, 0, sizeof(uint8_t) * 3);
  pBuf[0] = (uint8_t)((data >> 8) & 0xFF);
  pBuf[1] = (uint8_t)(data & 0xFF);
  pBuf[2] = calcCRC(data);

  return pBuf;
}
*/

/****************************** Read/Write Command Function ********************************/

void SCDwriteData(uint16_t cmd, uint8_t *pBuf, size_t size) {
  HAL_I2C_Mem_Write(&SCD4X_I2C_PORT, SCD4X_I2C_ADDR, cmd, 2, NULL, 0, 100);
}

size_t SCDreadData(uint16_t cmd, uint8_t *pBuf, size_t size) {
  HAL_I2C_Mem_Write(&SCD4X_I2C_PORT, SCD4X_I2C_ADDR, cmd, 2, NULL, 0, 100);
  HAL_I2C_Master_Receive(&SCD4X_I2C_PORT, SCD4X_I2C_ADDR, pBuf, size, 100);
  return size;
}

void readMeasurement(sSensorMeasurement_t * data) {
  uint8_t buf[9] = {0};
  SCDreadData(SCD4X_READ_MEASUREMENT, buf, sizeof(buf));
  data->CO2ppm = SCD4X_CONCAT_BYTES(buf[0], buf[1]);
  data->temp = -45 + 175 * (float)(SCD4X_CONCAT_BYTES(buf[3], buf[4])) / ((uint32_t)1 << 16);
  data->humidity = 100 * (float)(SCD4X_CONCAT_BYTES(buf[6], buf[7])) / ((uint32_t)1 << 16);
}

/* USER CODE END 0 */

/**
  * @brief  The application entry point.
  * @retval int
  */
int main(void)
{
  /* MCU Configuration--------------------------------------------------------*/

  /* Reset of all peripherals, Initializes the Flash interface and the Systick. */
  HAL_Init();

  /* Configure the system clock */
  SystemClock_Config();

  /* USER CODE BEGIN SysInit */
  ST7735_Unselect();
  /* USER CODE END SysInit */

  /* Initialize all configured peripherals */
  MX_GPIO_Init();
  MX_DMA_Init();
  MX_USART1_UART_Init();
  MX_I2C1_Init();
  MX_SPI2_Init();
  MX_IWDG_Init();
  MX_ADC1_Init();
  MX_TIM1_Init();
  MX_RTC_Init();
  MX_TIM4_Init();
  /* USER CODE BEGIN 2 */
  HAL_GPIO_WritePin(LED_GPIO_Port, LED_Pin, GPIO_PIN_SET);
  #ifdef DISPLAY_ST7735S
  ST7735_Init();
  ST7735_FillScreen(ST7735_BLACK);
  ST7735_WriteString(0, 0, "SCD41 init  ", Font_7x10, ST7735_WHITE, ST7735_BLACK);
  #endif
  #ifdef DISPLAY_1306
  ssd1306_Init();
  ssd1306_SetCursor(0, 0);
  ssd1306_WriteString("SCD41 init  ", Font_6x8, 0x01);
  ssd1306_UpdateScreen();
  #endif

  uint16_t serialBufer[3];
  serialBufer[0] = 0;
  serialBufer[1] = 0;
  serialBufer[2] = 0;
  //LED_PULSE
  enablePeriodMeasure(SCD4X_STOP_PERIODIC_MEASURE);  // Write: C4 0 D:3F 0 D:86 0
  HAL_Delay(500);
  //LED_PULSE
  if (getSerialNumber(serialBufer)) { // Write: C4 0 D:36 0 D:82 0 Read: C5 0 D:EA 0 D:AE 0 D:FA 0 D:B7 0 D:07 0 D:29 0 D:3B 0 D:BF Write: C4 0 D:21 0 D:B1 0
	#ifdef DISPLAY_ST7735S
	ST7735_WriteString(96, 0, "Ok", Font_7x10, ST7735_GREEN, ST7735_BLACK);
	#endif
	#ifdef  DISPLAY_1306
	  ssd1306_WriteString("Ok", Font_6x8, 0x01);
	  ssd1306_UpdateScreen();
	  HAL_Delay(300);
	#endif
  } else {
	#ifdef DISPLAY_ST7735S
	ST7735_WriteString(96, 0, "Fail", Font_7x10, ST7735_RED, ST7735_BLACK);
	#endif
	#ifdef  DISPLAY_1306
	  ssd1306_WriteString("Failed.", Font_6x8, 0x01);
	  ssd1306_UpdateScreen();
	  HAL_Delay(300);
	#endif
  }

  #ifdef CO2_DEBUG
  sprintf(SndBuffer, "S0:%d S1:%d S2:%d   \r\n", serialBufer[0], serialBufer[1], serialBufer[2]);
  HAL_UART_Transmit(&huart1, (uint8_t *) SndBuffer, sizeof(SndBuffer), 1000);
  HAL_Delay(500);
  #endif
  enablePeriodMeasure(SCD4X_START_PERIODIC_MEASURE);
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

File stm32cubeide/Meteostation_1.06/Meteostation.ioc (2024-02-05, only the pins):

Mcu.UserName=STM32F103C8Tx
PA6.GPIO_Label=PULSE_GM
PB11.Signal=GPIO_Output
PB15.Signal=SPI2_MOSI
PB13.Signal=SPI2_SCK
PA15.GPIO_Label=POWER_PULSE
PA12.Signal=GPIO_Output
PB6.Signal=USART1_TX
PB12.GPIO_Label=Eth_CS
PA10.GPIO_Label=ST7735S_DC
PB7.Signal=USART1_RX
PA8.Signal=GPIO_Output
PB9.Signal=I2C1_SDA
PA6.Signal=GPXTI6
PA10.Signal=GPIO_Output
PA15.Signal=GPIO_Output
PB9.GPIO_Label=BME280_SDA
PA9.GPIO_Label=ST7735S_CS
PB11.GPIO_Label=ST7735S_RESET
PA12.GPIO_Label=LED
PB8.GPIO_Label=BME280_SCL
PA8.GPIO_Label=Eth_rst
PA9.Signal=GPIO_Output
PB14.Signal=SPI2_MISO
PA5.Signal=ADCx_IN5
PA5.GPIO_Label=FB
PB8.Signal=I2C1_SCL
PB12.Signal=GPIO_Output

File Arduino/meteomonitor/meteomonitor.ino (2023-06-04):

#include <Ethernet.h>
//#include <Wire.h>
//#include <SPI.h>
#include <Adafruit_BME280.h>

//#define SERIAL_OUT
#define ZABBIXPORT 10051      // Zabbix erver Port
#define ZABBIXMAXLEN 128
#define ZABBIXAGHOST "Meteo_4"  // Zabbix item's host name
#define ZABBIXSENDPERIOD 300 // Period in secoonds
#define wdt_on false
#define MEASSURE_INTERVAL 10000
#define BMEADDR 0x76
#define SENSEAIR

#ifdef SENSEAIR
#include <SoftwareSerial.h>
#endif

#if wdt_on
#include <avr/wdt.h>
#endif

#if defined(WIZ550io_WITH_MACADDRESS) // Use assigned MAC address of WIZ550io
  ;
#else
  byte mac[] = { 0x00, 0xAA, 0xBB, 0xCC, 0xDE, 0x46 };
#endif
#define LED A3      /* Моргалка */
#define ETHReset 7  /* Сброс ethernet интерфейса */

//#define OLED
#ifdef OLED
//#define USE_MICRO_WIRE
#include <GyverOLED.h>
GyverOLED<SSD1306_128x32, OLED_NO_BUFFER> oled;
#endif

Adafruit_BME280 bme; // I2C
unsigned long ms_old, ms;
unsigned statBME280;

uint8_t res[ZABBIXMAXLEN];
EthernetClient client;
IPAddress server(192, 168, 1, 6); // Zabbix server IP.
String str;

/* SenseAir S8 
  RxD -- 8
  TxD -- 9
*/
#ifdef SENSEAIR
SoftwareSerial K_30_Serial(8, 9); // Программный порт
byte readCO2[] =  {0xFE, 0X44, 0X00, 0X08, 0X02, 0X9F, 0X25}; //Команда для запроса показаний CO2 с датчика
//byte readTemp[] = {0xFE, 0X44, 0X00, 0X12, 0X02, 0X94, 0X45}; //Команда для запроса показаний температуры с датчика
//byte readRH[] =   {0xFE, 0x44, 0x00, 0x14, 0x02, 0x97, 0xE5}; //Команда для запроса показаний влажности с датчика
byte response[] = {0, 0, 0, 0, 0, 0, 0}; //массив для ответа от датчика
#endif
String valPress, valRH, valTemp, valCO2;
double val;

void sendToZabbix(String key, float val) {
  int len;
  str = "{\"request\":\"sender data\",\"data\":[{\"host\":\"";
  str = str + ZABBIXAGHOST;
  str = str + "\",\"key\":\""; 
  str = str + key;
  str = str + "\",\"value\":\"";
  str = str + val;
  str = str + "\"}]}";
  len = str.length();
  res[0] = 'Z';
  res[1] = 'B';
  res[2] = 'X';
  res[3] = 'D';
  res[4] = 0x01;
  res[5] = str.length();
  res[6] = 0;
  res[7] = 0;
  res[8] = 0;
  res[9] = 0;
  res[10] = 0;
  res[11] = 0;
  res[12] = 0;
  str.getBytes(&(res[13]), ZABBIXMAXLEN - 12);
  len = len + 13;
  #ifdef SERIAL_OUT
  for( int i = 13; i < len + 13; i++) {
    Serial.print((char)(res[i]));
  }
  Serial.println();
  #endif
  if (client.connect(server, ZABBIXPORT)) {
    client.write(res, len);
    #if wdt_on
    wdt_reset();
    #endif
  } else {
    #ifdef SERIAL_OUT
    Serial.println("Not conn.");
    #endif
  }      
  client.stop();
}

void setup() {
  #if wdt_on
    wdt_disable();
  #endif
#ifdef SERIAL_OUT
  Serial.begin(9600);
  while(!Serial);
  delay(1000);
#endif

#ifdef OLED
  oled.init();
#endif

  pinMode(LED, OUTPUT);
  digitalWrite(LED, HIGH);
  #ifdef SENSEAIR
  K_30_Serial.begin(9600);
  #endif
  pinMode(ETHReset, OUTPUT);
  statBME280 = bme.begin(BMEADDR);
#ifdef SERIAL_OUT
  Serial.println();
  Serial.print("BME280-");
  if (!statBME280) {
    Serial.println("No");
  } else {
    Serial.println("Ok.");
  }
    Serial.print("Eth-");
#endif
  digitalWrite(ETHReset, LOW);
  digitalWrite(ETHReset, HIGH);
  ms_old = millis();
  #if wdt_on
    wdt_enable(WDTO_8S);
  #endif
  
    if (Ethernet.begin(mac) == 0) {
  #ifdef SERIAL_OUT
      Serial.println("FALSE.");
  #endif
    }
  #ifdef SERIAL_OUT
      Serial.println(Ethernet.localIP());
  #endif
    digitalWrite(LED, LOW);
}

void loop() {
  ms = millis();
  if (ms - ms_old > MEASSURE_INTERVAL) {
    digitalWrite(LED, HIGH);
    if (statBME280) {
      val = bme.readTemperature();
      sendToZabbix("TEMPERATURE", val);
      valTemp = "T:" + String(val);
      val = bme.readPressure() * 0.0075006156130264F; // From Pa to mmHg
      sendToZabbix("PRESSURE", val);
      valPress = "P:" + String(val);
      val = bme.readHumidity();
      sendToZabbix("HUMMIDITY", val);
      valRH = "H:" + String(val);
    }
    /* CO2 read */
    #ifdef SENSEAIR
    while (!K_30_Serial.available()) {
      K_30_Serial.write(readCO2, 7);
      delay(50);
    }
    int timeout = 0;                        // Счетчик таймаута
    while (K_30_Serial.available() < 7 ) {  // Ждем ответа 7 байт
      if (timeout++ > 10) {                 // Проверка таймаута
        while (K_30_Serial.available())
          K_30_Serial.read();
        break;
      }
      delay(50);
    }
    for (int i = 0; i < 7; i++)  {
      response[i] = K_30_Serial.read();
    }
    val = response[3] * 256 + response[4];
    if (val > 300) {
      sendToZabbix("CO2", val);
      valCO2 = "CO2:" + String((int) val);
    }
    #endif
    //sendRequest(readTemp);
    //valTemp = "Temp: " + String(val / 100) + " C";
    //sendRequest(readRH);
    //valRH = "RH: " + String(val / 100) + " %";
    #ifdef OLED
    oled.clear();
    oled.setCursor(0, 0);
    oled.print(valCO2);
    oled.setCursor(0, 1);
    oled.print(valTemp);
    oled.setCursor(0, 2);
    oled.print(valRH);
    oled.setCursor(0, 3);
    oled.print(valPress);
    oled.update();
    #endif
    #ifdef SERIAL_OUT
    Serial.println(valCO2);
    Serial.println(valTemp);
    Serial.println(valRH);
    Serial.println(valPress);
    #endif
   ms_old = ms;
   digitalWrite(LED, LOW);
  }
  
  #if wdt_on
    wdt_reset();
  #endif
}

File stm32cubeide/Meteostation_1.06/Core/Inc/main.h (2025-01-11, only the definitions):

#define COLUMN0 0
#define COLUMN1 54
#define COLUMN2 97
#define BIT0 0x01
#define BIT1 0x02
#define BIT2 0x04
#define BIT3 0x08
#define BIT4 0x10
#define BIT5 0x20
#define BIT6 0x40
#define BIT7 0x80
#define TRUE 1
#define FALSE 0
#define LED_PULSE LED_GPIO_Port->BSRR = (uint32_t)LED_Pin; LED_GPIO_Port->BSRR = (uint32_t)LED_Pin << 16u;
#define TP_PULSE GPIOA->BSRR = (uint32_t)GPIO_PIN_15; GPIOA->BSRR = (uint32_t)GPIO_PIN_15 << 16u;
#define POWER_PULSE POWER_PULSE_GPIO_Port->BSRR = (uint32_t)POWER_PULSE_Pin; POWER_PULSE_GPIO_Port->BSRR = (uint32_t)POWER_PULSE_Pin << 16u;
#define POWER_VOLTAGE 960
#define POWER_CONVERT 0.416f
#define TRUST_INTERVAL 900 /* 3 sigma - 10%*/
#define GM_CPS2URh 9.6
#define GM_SELF_FONE 0.5	/* Собственный фон трубки */
#define MEAS_INTERVAL 1000
#define ANEM_INTERVAL 10000		/* Интервал опроса анемометра */
#define MEAS_CO2_INTERVAL1 1000
#define MEAS_CO2_INTERVAL2 5000
#define ZABB_MEAS_INTERVAL 10000
#define NTP_INTERVAL 60000 /* 0.1 час */
#define CO2_NOMINAL 800.0f
#define CO2_MAXIMUM 1000.0f
#define FB_Pin GPIO_PIN_5
#define FB_GPIO_Port GPIOA
#define PULSE_GM_Pin GPIO_PIN_6
#define PULSE_GM_GPIO_Port GPIOA
#define PULSE_GM_EXTI_IRQn EXTI9_5_IRQn
#define ST7735S_RESET_Pin GPIO_PIN_11
#define ST7735S_RESET_GPIO_Port GPIOB
#define Eth_CS_Pin GPIO_PIN_12
#define Eth_CS_GPIO_Port GPIOB
#define Eth_rst_Pin GPIO_PIN_8
#define Eth_rst_GPIO_Port GPIOA
#define ST7735S_CS_Pin GPIO_PIN_9
#define ST7735S_CS_GPIO_Port GPIOA
#define ST7735S_DC_Pin GPIO_PIN_10
#define ST7735S_DC_GPIO_Port GPIOA
#define LED_Pin GPIO_PIN_12
#define LED_GPIO_Port GPIOA
#define POWER_PULSE_Pin GPIO_PIN_15
#define POWER_PULSE_GPIO_Port GPIOA
#define BME280_SCL_Pin GPIO_PIN_8
#define BME280_SCL_GPIO_Port GPIOB
#define BME280_SDA_Pin GPIO_PIN_9
#define BME280_SDA_GPIO_Port GPIOB
#define INIT_FINISH_TEXT "Init finish.\r\n"
#define RESTART_TOUT "\r\nTime out, restart.\r\n"
#define START_TEXT "\r\nMeteostation start.\r\n"
#define DHCP_SOCKET     0
#define DNS_SOCKET      1
#define TCP_SOCKET		2
#define ANM_SOCKET		3
#define DATA_BUF_SIZE   1024
#define ZABBIXAGHOST	"Meteo"  // Default hostname.
#define ZABBIXPORT		10051
#define ANEMOMETERPORT	1600
#define ZABBIXMAXLEN	128
#define MAC_ADDRESS		0x00, 0x11, 0x22, 0x33, 0x44, 0xf7

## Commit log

2022-09-04 удалено: Documents/12_100229_1_85526.pdf удалено: Documents/2022_04_03_20_00_22_110.png удалено: Documents/Diagram.pdf удалено: Documents/IMG_20220105_221915.jpg удалено: Documents/IMG_20220105_22192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
    [AnalogMux.ods, Anemometer Debug.cfg, Anemometr.kicad_pcb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]
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2022-09-05 изменено: kicad/Meteostation_3/Meteostation.kicad_pcb изменено: kicad/Meteostation_3/Meteostation.kicad_pcb-bak изменено: kicad/Meteostation_3/Meteostation.sch изменено: kicad/Meteostation_3/Meteosta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
    [Meteostation.kicad_pcb, Meteostation.sch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]
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2022-09-08 изменено: FreeCAD/box.FCStd изменено: FreeCAD/box.stl новый файл: kicad/Meteostation_4/Meteostation-cache.lib новый файл: kicad/Meteostation_4/Meteostation-rescue.bck новый файл: kicad/Meteostation_4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
    [Meteostation.kicad_pcb, Meteostation.sch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]
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2022-09-09 новый файл: Documents/5N10.pdf изменено: kicad/Meteostation_4/Meteostation.kicad_pcb изменено: kicad/Meteostation_4/Meteostation.kicad_pcb-bak изменено: kicad/Meteostation_4/Meteostation.sch изменено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
    [Meteostation.kicad_pcb, Meteostation.sch]
2022-09-11 изменено: kicad/Meteostation_4/Meteostation-cache.lib изменено: kicad/Meteostation_4/Meteostation-rescue.lib изменено: kicad/Meteostation_4/Meteostation.kicad_pcb изменено: kicad/Meteostation_4/Meteo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
    [Meteostation.kicad_pcb, Meteostation.sch]
2022-09-13 изменено: kicad/Meteostation_4/gerber/Meteostation.zip новый файл: stm32cubeide/Meteostation/.cproject новый файл: stm32cubeide/Meteostation/.mxproject новый файл: stm32cubeide/Meteostation/.project 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
    [Meteostation Debug.cfg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]
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2022-09-19 изменено: kicad/Meteostation_4/Meteostation.kicad_pcb изменено: kicad/Meteostation_4/Meteostation.kicad_pcb-bak изменено: kicad/Meteostation_4/Meteostation.sch изменено: kicad/Meteostation_4/Meteosta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
    [Meteostation.kicad_pcb, Meteostation.sch]
2022-09-19 изменено: kicad/Meteostation_4/Meteostation.sch изменено: kicad/Meteostation_4/Meteostation.sch-bak изменено: stm32cubeide/Meteostation/.mxproject изменено: stm32cubeide/Meteostation/Core/Inc/main.h 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
    [Meteostation.sch]
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2022-09-28 новый файл: kicad/BME280/BME280-cache.lib новый файл: kicad/BME280/BME280.kicad_pcb новый файл: kicad/BME280/BME280.kicad_pcb-bak новый файл: kicad/BME280/BME280.pro новый файл: kicad/BME280/BME280.s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
    [BME280.kicad_pcb, BME280.sch]
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2022-10-28 изменено: kicad/Meteostation_4/Meteostation.kicad_pcb изменено: kicad/Meteostation_4/Meteostation.kicad_pcb-bak изменено: kicad/Meteostation_4/Meteostation.pro изменено: kicad/Meteostation_4/Meteosta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
    [Meteostation.kicad_pcb, Meteostation.sch]
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2022-11-11 изменено: kicad/Meteostation_4/Meteostation.kicad_pcb изменено: kicad/Meteostation_4/Meteostation.kicad_pcb-bak изменено: kicad/Meteostation_4/Meteostation.sch изменено: kicad/Meteostation_4/Meteosta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
    [Meteostation.kicad_pcb, Meteostation.sch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]
2022-11-17 изменено: kicad/Meteostation_4/Meteostation-rescue.lib изменено: kicad/Meteostation_4/gerber/Border.gbr изменено: kicad/Meteostation_4/gerber/Bottom.gbr изменено: kicad/Meteostation_4/gerber/MaskBott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
    [VL53L0x.kicad_pcb, VL53L0x.sch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]
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2022-12-05 изменено: kicad/Meteostation_4/gerber/Border.gbr изменено: kicad/Meteostation_4/gerber/Bottom.gbr изменено: kicad/Meteostation_4/gerber/MaskBottom.gbr изменено: kicad/Meteostation_4/gerber/MaskTop.gb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
    [Border.gbr, Bottom.gbr, MaskBottom.gbr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]
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2023-01-07 изменено: kicad/Meteostation_4/Meteostation.sch изменено: kicad/Meteostation_4/Meteostation.sch-bak изменено: stm32cubeide/Meteostation/.mxproject изменено: stm32cubeide/Meteostation/.settings/langua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
    [Meteostation.sch]
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2023-01-09 изменено: Documents/sheet.png изменено: kicad/Meteostation_4/Meteostation-cache.lib изменено: kicad/Meteostation_4/Meteostation.kicad_pcb изменено: kicad/Meteostation_4/Meteostation.kicad_pcb-bak изм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
    [Meteostation.kicad_pcb, Meteostation.sch]
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2023-06-04 изменено: Arduino/meteomonitor/meteomonitor.ino изменено: FreeCAD/GM_case_top.FCStd изменено: kicad/Meteostation_4/Meteostation-cache.lib изменено: kicad/Meteostation_4/Meteostation-rescue.lib измене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
    [GM_case_top.FCStd, Meteostation.kicad_pcb, Meteostation.sch]
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2023-06-07 изменено: kicad/Meteostation_4/Meteostation.kicad_pcb изменено: kicad/Meteostation_4/Meteostation.kicad_pcb-bak изменено: kicad/Meteostation_4/Meteostation.sch изменено: kicad/Meteostation_4/Meteosta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
    [Meteostation.kicad_pcb, Meteostation.sch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]
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2024-02-05 изменено: FreeCAD/GM_case.FCStd изменено: kicad/BME280/BME280.kicad_pcb изменено: kicad/Meteostation_4/Meteostation-rescue.lib изменено: kicad/Meteostation_4/Meteostation.kicad_pcb изменено: stm32cub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
    [BME280.kicad_pcb, GM_case.FCStd, Meteostation.kicad_pcb]
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2024-12-31 новый файл: stm32cubeide/Meteostation_1.06/.cproject новый файл: stm32cubeide/Meteostation_1.06/.mxproject новый файл: stm32cubeide/Meteostation_1.06/.project новый файл: stm32cubeide/Meteostation_1.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
    [Meteostation Debug.cfg, Meteostation.cfg]
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

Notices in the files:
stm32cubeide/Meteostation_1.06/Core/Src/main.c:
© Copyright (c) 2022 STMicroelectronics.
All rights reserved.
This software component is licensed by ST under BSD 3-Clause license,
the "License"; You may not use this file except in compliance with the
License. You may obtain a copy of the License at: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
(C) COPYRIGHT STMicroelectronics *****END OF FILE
